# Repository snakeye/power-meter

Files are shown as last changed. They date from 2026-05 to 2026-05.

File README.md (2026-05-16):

# Power Meter

Power Meter is a microcontroller-based current consumption meter.
It samples current with an external ADC, computes rolling values in firmware, and displays live readings on a small OLED screen.

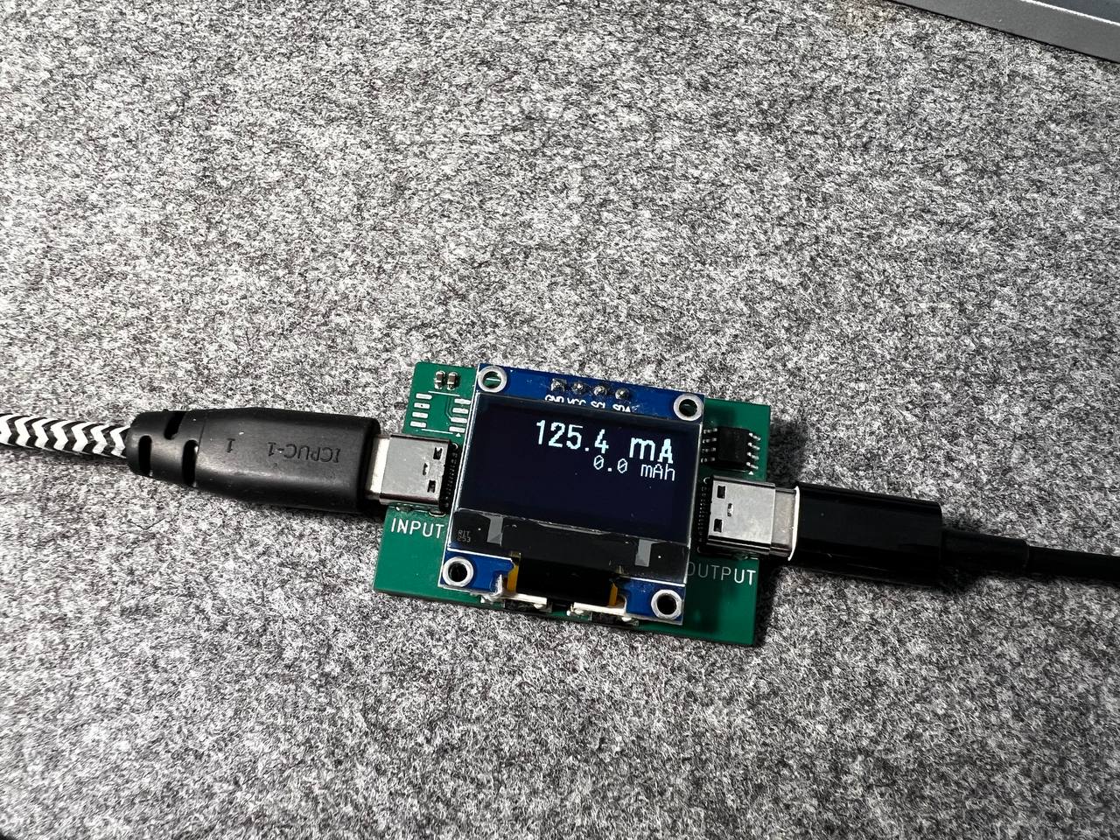
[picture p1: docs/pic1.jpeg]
The device


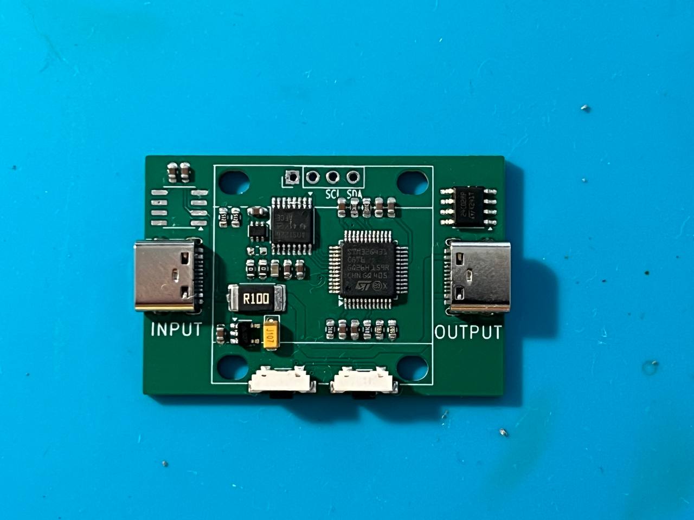
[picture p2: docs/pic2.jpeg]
PCB


This repository is organized around two parts:
- `firmware/` - PlatformIO project with STM32 firmware
- `hardware/` - KiCad schematic/PCB and symbol/footprint libraries

## Project status

This is an early public version. Core measurement and display flow is implemented, while some features are still work in progress.

Implemented:
- ADC continuous sampling using ADS1220 DRDY interrupt
- Raw-to-current conversion (microamps)
- On-screen display of averaged current, elapsed time, and accumulated charge estimate
- Reset of measurement session from button A

Not implemented yet / needs refinement:
- Persistent configuration load/save (`loadConfig`, `saveConfig` are currently stubs)
- Button B action (handler is empty)
- Charge accumulation algorithm validation and unit correctness improvements

## Quick start

Prerequisites:
- PlatformIO CLI installed
- ST-Link connected to target board

Build firmware:

```bash
cd firmware
platformio run
```

Flash firmware:

```bash
cd firmware
platformio run -t upload
```

Current default PlatformIO environment targets STM32G431C8 (`STM32G431C8T6`).

## Documentation

Use these documents as the main reference:
- `docs/overview.md` - project overview and data flow
- `docs/architecture.md` - system architecture and runtime model
- `docs/firmware.md` - firmware modules and behavior
- `docs/hardware.md` - hardware components and repository artifacts
- `docs/build-and-flash.md` - setup, build, flash, and debug workflow
- `docs/roadmap.md` - known issues and next milestones

## Notes for contributors

- Prefer documenting real current behavior over intended behavior.
- Keep units explicit (`uA`, `mA`, `mAh`, `us`, `ms`) in code and docs.
- If you change measurement math, update `docs/firmware.md` accordingly.

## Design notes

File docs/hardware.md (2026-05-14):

## Hardware

Hardware design files are stored in `hardware/` and maintained in KiCad format.

## Main components

- ADS1220 - 24-bit external ADC for precision sampling
- INA213 - current-sense amplifier
- 0.1 Ohm shunt resistor (100 mOhm)
- STM32 microcontroller (firmware currently targets STM32G431C8)
- 128x64 I2C OLED display (SSD1306 compatible)
- M24C02 external I2C EEPROM for config persistence
- Two user buttons (A/B)

## External EEPROM (M24C02)

Configuration persistence uses a discrete `M24C02` connected to the main I2C bus.

- Device type: `M24C02` (`2 Kbit = 256 bytes`)
- I2C base address: `0x50`
- Address pins: `A0/A1/A2 -> GND` (fixed address `0x50`)
- Typical page size: `8 bytes` (page write boundary must be respected)

Firmware write behavior:

- Data is split into 8-byte page writes.
- After each page write, firmware waits for device ready using ACK polling.
- Config data includes CRC32 to detect corruption.

Because OLED display shares the same I2C bus, EEPROM writes should remain infrequent (configuration or calibration events only).

## Measurement chain and equations

Current measurement path in this project:

1. Load current flows through shunt resistor.
2. Shunt creates a differential voltage proportional to current.
3. INA213 amplifies this shunt voltage.
4. ADS1220 digitizes amplified analog voltage.
5. Firmware converts ADC counts to current in `uA`.

Core equations:

- `Vshunt = Iload * Rshunt`
- `Vamp = GainINA * Vshunt = Iload * Rshunt * GainINA`
- `raw ~= (Vamp / Vref) * 2^23`
- `Iload = raw * Vref / (Rshunt * GainINA * 2^23)`

For the current firmware constants:

- `Rshunt = 0.1 Ohm`
- `GainINA = 50`
- `Vref = 2.048 V` (ADS1220 internal reference)
- `2^23 = 8,388,608`

Current per ADC count:

- `I_per_count = Vref / (Rshunt * GainINA * 2^23)`
- `I_per_count = 2.048 / (0.1 * 50 * 8,388,608) A`
- `I_per_count ~= 4.8828125e-8 A`
- `I_per_count ~= 48.828125 nA ~= 0.048828125 uA`

Counts per milliamp:

- `raw_per_mA = 0.001 / I_per_count`
- `raw_per_mA ~= 20,480 counts/mA`

Equivalent check values:

- `10 mA` -> about `204,800` counts
- `100 mA` -> about `2,048,000` counts
- `500 mA` -> about `10,240,000` counts (already above nominal 2^23 full scale and therefore limited by analog output swing and ADC range)

## Expected current range with INA213 at 3.3V

The practical upper current limit is usually set by INA213 output headroom before ADC full scale becomes the bottleneck.

Idealized upper bound using output rail as limit:

- `Imax_theory = Vout_max / (Rshunt * GainINA)`
- With `Vout_max = 3.3V`: `Imax_theory = 3.3 / (0.1 * 50) = 0.66A`

Real analog front-end usually cannot swing exactly to the rail. Practical range is therefore lower.

Recommended engineering expectation:

- Typical safe range: about `0 ... 0.55A`
- Practical observed limit for many boards: about `0.55 ... 0.65A`

Exact value should be validated on the assembled board and across temperature.

## Resolution vs real accuracy

The ADC quantization step is very small (`~48.8 nA/count`), but system accuracy is dominated by analog and calibration effects, not by ADC LSB.

Primary contributors:

- Shunt tolerance: `0.5%` scale error baseline.
- INA gain error and drift: additional scale and temperature-dependent error.
- Zero offset and drift: dominant at low currents.
- Noise (INA + ADS1220 + layout/EMI): causes short-term fluctuation.

With current firmware defaults, `adcZeroOffset = 5600` counts corresponds to approximately:

- `5600 * 0.048828125 uA ~= 273.44 uA`

This means that without robust zero calibration, low-current measurements can have large relative error.

## Practical accuracy expectations (before full calibration)

These are engineering expectations for this architecture, not guaranteed specs.

- `0.5 ... 5 mA`: often offset/noise limited, relative error can be high.
- `5 ... 100 mA`: generally usable, accuracy improves as signal dominates offset.
- `100 ... 600 mA`: usually dominated by scale error (shunt tolerance + gain error), often in low single-digit percent range after basic zeroing.

To tighten numbers, perform board-level calibration with known current loads.

## Charge integration units and conversion

Correct physical integration is:

- `dQ = I * dt`

If firmware stores:

- `I` in `uA`
- `dt` in `us`

then accumulated charge unit is:

- `Q` in `uA*us`

Conversion to milliamp-hours:

- `1 mAh = 1000 uA * 3600 s`
- `1 s = 1,000,000 us`
- `1 mAh = 1000 * 3600 * 1,000,000 = 3,600,000,000,000 uA*us`

Therefore:

- `mAh = Q_uA_us / 3,600,000,000,000`

When implemented this way, accumulated charge is correctly tied to measured current and elapsed time and does not break when ADC sample rate changes.

## Calibration recommendations

For robust measurements, use at least a 3-point procedure:

1. Zero-current calibration: record and store offset after warm-up.
2. Mid-scale calibration: validate gain around a representative working current.
3. High-scale calibration: validate near upper operating current without clipping.

Suggested firmware calibration outputs:

- `adcZeroOffset` (offset term)
- gain correction factor (multiplicative term)

Re-run calibration when changing shunt value, analog supply conditions, PCB revision, or thermal environment.

## Repository artifacts

Primary KiCad project files:
- `hardware/power-meter.kicad_pro`
- `hardware/power-meter.kicad_sch`
- `hardware/power-meter.kicad_pcb`

Libraries and custom symbols/footprints:
- `hardware/power-meter.kicad_sym`
- `hardware/INA213BIDCKT.kicad_sym`
- `hardware/STM32G431.kicad_sym`
- `hardware/power-meter.pretty/`

## Consistency note

Earlier project notes referenced STM32F103. Current firmware configuration and board definition target STM32G431C8.

If you are assembling hardware, verify the exact MCU variant against both:
- firmware board config (`firmware/platformio.ini`, `firmware/boards/genericSTM32G431C8.json`)
- KiCad schematic and BOM

## Suggested hardware documentation additions

For future public releases, consider adding:
- validated BOM with manufacturer part numbers
- board revision history
- calibration/test procedure
- connector and pinout diagrams

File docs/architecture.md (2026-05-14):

## Architecture

This project is split into hardware design artifacts and firmware runtime logic.

## Top-level components

- `hardware/` contains the electrical design in KiCad.
- `firmware/` contains embedded software for acquisition, processing, and UI.

## Firmware module map

- `src/main.cpp`
  - System setup
  - Button event wiring
  - Main loop tick handlers
- `src/adc.h`, `src/adc.cpp`
  - ADS1220 setup
  - DRDY interrupt handler
  - Measurement buffers and counters
  - Session reset and charge accumulator state
- `src/display.h`, `src/display.cpp`
  - OLED init (U8g2)
  - Periodic rendering of values
- `src/util.h`, `src/util.cpp`
  - ADC raw count to current conversion
  - 64-bit microsecond timestamp helper
- `src/config.h`, `src/config.cpp`
  - Runtime config structure and defaults
  - Persistence API placeholders (currently not implemented)

## Runtime model

### Setup phase

`setup()` performs initialization in this order:

1. I2C bus init
2. Display init
3. ADC init and ADC runtime configuration
4. Button A and B setup + click callbacks
5. Config load (currently stubbed)
6. Measurement data reset

### Main loop phase

`loop()` does not poll ADC directly. It:

- Advances button state machines (`btnA.tick()`, `btnB.tick()`).
- Schedules periodic display updates every 100 ms via `RecurringTask::interval(100, displayUpdate)`.

### Interrupt-driven acquisition

The ADS1220 DRDY pin is attached to `onAdcDataReadyInterrupt()`.

For each sample:

1. Read raw ADC data.
2. Apply configured zero offset.
3. Clamp negative values to zero.
4. Convert to current (`uA`).
5. Store current and time interval in fixed-size ring buffers.
6. Update counters/index and charge accumulator state.

## State ownership

Acquisition state is global and mostly held in `adc.cpp`:

- `measurements[]`, `intervals[]`
- `last_measurement_idx`, `measurements_count`
- `totalCharge`
- `tsStart`

Display logic reads this shared state to render user-visible metrics.

## Concurrency notes

- Measurements are updated in interrupt context and read in main-loop context.
- Several shared fields are marked `volatile`, but there is no explicit critical section around multi-field snapshots.
- As the project evolves, consider atomic snapshot/copy strategy for display calculations.

## Known architecture gaps

- Persistence layer exists only as API shape.
- Input model currently uses one active action (button A reset).
- Charge accumulation semantics require verification and likely redesign.

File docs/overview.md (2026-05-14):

## Overview

Power Meter is an embedded current measurement device built around an STM32 microcontroller, an ADS1220 external ADC, and an INA213 current-sense amplifier.

The firmware continuously samples current, stores recent values in a small ring buffer, computes an average for display, and presents runtime information on a 128x64 OLED.

## Goals

- Measure low current consumption with better resolution than basic MCU ADC paths.
- Provide simple on-device readout for quick bench testing.
- Keep the firmware compact and easy to iterate.

## Repository structure

- `firmware/` - PlatformIO project (Arduino framework on STM32)
- `hardware/` - KiCad project files (schematic, PCB, symbols, footprints)
- `docs/` - project documentation

## High-level data flow

1. ADS1220 performs continuous conversions.
2. DRDY pin triggers an interrupt on each new sample.
3. Interrupt handler reads raw ADC data and applies zero offset.
4. Raw counts are converted to current in microamps (`uA`).
5. Sample and interval are written to ring buffers.
6. UI task periodically renders average current, elapsed time, and charge estimate.

## Current maturity snapshot

Working now:
- ADC interrupt-driven sampling
- Current conversion and averaging
- OLED rendering loop
- Session reset on button A click

Still pending:
- EEPROM-backed config persistence API (`loadConfig` / `saveConfig`)
- Button B feature
- Charge integration model review for physical correctness

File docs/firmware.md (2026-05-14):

## Firmware

Firmware lives in `firmware/` and is built with PlatformIO using the Arduino framework for STM32.

## Build configuration

Main config file: `firmware/platformio.ini`

Current defaults:
- Platform: `ststm32`
- Framework: `arduino`
- Upload/debug: `stlink`
- Default env: `STM32G431C8T6`

Available environments:
- `STM32G431C8T6` (default)
- `bluepill` (legacy/alternate)

Custom board definition:
- `firmware/boards/genericSTM32G431C8.json`

## External libraries

- `ADS1220_WE` - ADS1220 ADC driver
- `U8g2` - OLED graphics
- `OneButton` - debounced button events
- `RecurringTask` - periodic task helper
- `Wire`, `SPI` - bus interfaces

## Module behavior

### `main.cpp`

- Initializes buses and peripherals.
- Registers button click handlers.
- Calls `loadConfig()` and `adcResetData()`.
- Runs button tick logic and display update scheduler in `loop()`.

Button actions:
- Button A click: resets current session data.
- Button B click: currently no action.

### `adc.cpp`

- Owns ADS1220 instance and SPI bus binding.
- Configures ADC for continuous conversion mode.
- Attaches falling-edge interrupt on DRDY.
- Converts raw ADC values to current via `convertRawToCurrent_uA()`.
- Stores values in fixed-size ring buffers (`measurements_buffer_size = 20`).

Data kept in global state:
- Samples: `measurements[]` in `uA`
- Per-sample delta: `intervals[]` in `us`
- Counters: `last_measurement_idx`, `measurements_count`
- Session start: `tsStart` in `ms`
- Accumulator: `totalCharge` (currently used as displayed charge estimate)

### `display.cpp`

- Uses `U8G2_SSD1306_128X64_NONAME_F_HW_I2C`.
- Computes average current over available ring buffer entries.
- Renders:
  - average current in `mA` with one decimal
  - charge estimate in `mAh` with one decimal (from `totalCharge` in `uA*us`)
  - elapsed time as `HH:MM:SS`

Refresh cadence is controlled externally from `loop()` at 100 ms.

### `util.cpp`

- `convertRawToCurrent_uA(rawValue)` converts ADC counts to microamps using:
  - reference voltage (`config.referenceVoltage`, mV)
  - INA213 gain (`ina213gain`)
  - shunt resistance (`shuntResistance`, mOhm)
  - ADC resolution (`2^23`)
- `get64bitMicros()` extends Arduino `micros()` to a monotonic 64-bit timeline using overflow tracking.

### `config.cpp`

- Declares default runtime config values:
  - `referenceVoltage = 2048` mV
  - `adcZeroOffset = 5600`
  - `adcGain = 1`
- Uses external I2C EEPROM `M24C02` at address `0x50` (A0/A1/A2 tied to GND).
- Stores config as a versioned block with CRC32 validation.
- `loadConfig()` reads from EEPROM, validates header/ranges/CRC, and falls back to defaults on failure.
- `saveConfig()` writes config using 8-byte page writes with ACK polling.

Stored block layout:

- `magic` (`0x504D4346`)
- `version` (`1`)
- `reserved`
- `Config`
- `crc32` (computed over all previous bytes in block)

## Pin mapping

Defined in `firmware/src/config.h`:

- I2C: `PA8` (SDA), `PA9` (SCL)
- ADS1220 SPI: `PA15` (CS), `PB3` (SCK), `PB4` (MISO), `PB5` (MOSI)
- ADS1220 DRDY: `PB15`
- Buttons: `PB7` (A), `PB9` (B)

## Known limitations

- UI and ISR share state without explicit snapshot synchronization.
- ADC error handling/recovery paths are minimal.

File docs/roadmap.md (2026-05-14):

## Roadmap

This roadmap reflects the current codebase state and practical next steps.

## Near-term priorities

1. Implement configuration persistence
   - Complete `loadConfig()` / `saveConfig()` with EEPROM layout and CRC validation.
   - Add safe defaults and versioning for future config changes.

2. Validate and fix charge accumulation
   - Revisit integration math and target units.
   - Add tests or offline validation scripts with known waveforms.

3. Complete input model
   - Define button B function (for example mode switch, calibration, or hold/reset behavior).
   - Add user feedback on screen for state changes.

4. Improve ISR/main-loop data consistency
   - Introduce snapshot logic or lock-free pattern for coherent display reads.
   - Reduce risk of partial multi-variable reads during rendering.

## Mid-term improvements

- Calibration workflow for zero offset and scaling factors
- Error detection and recovery (ADC init/read failures)
- Optional serial telemetry export for logging
- Power and noise characterization documentation

## Public-project readiness

- Add LICENSE file
- Add CONTRIBUTING guide
- Add issue templates for bug reports and feature requests
- Add hardware revision and tested setup matrix

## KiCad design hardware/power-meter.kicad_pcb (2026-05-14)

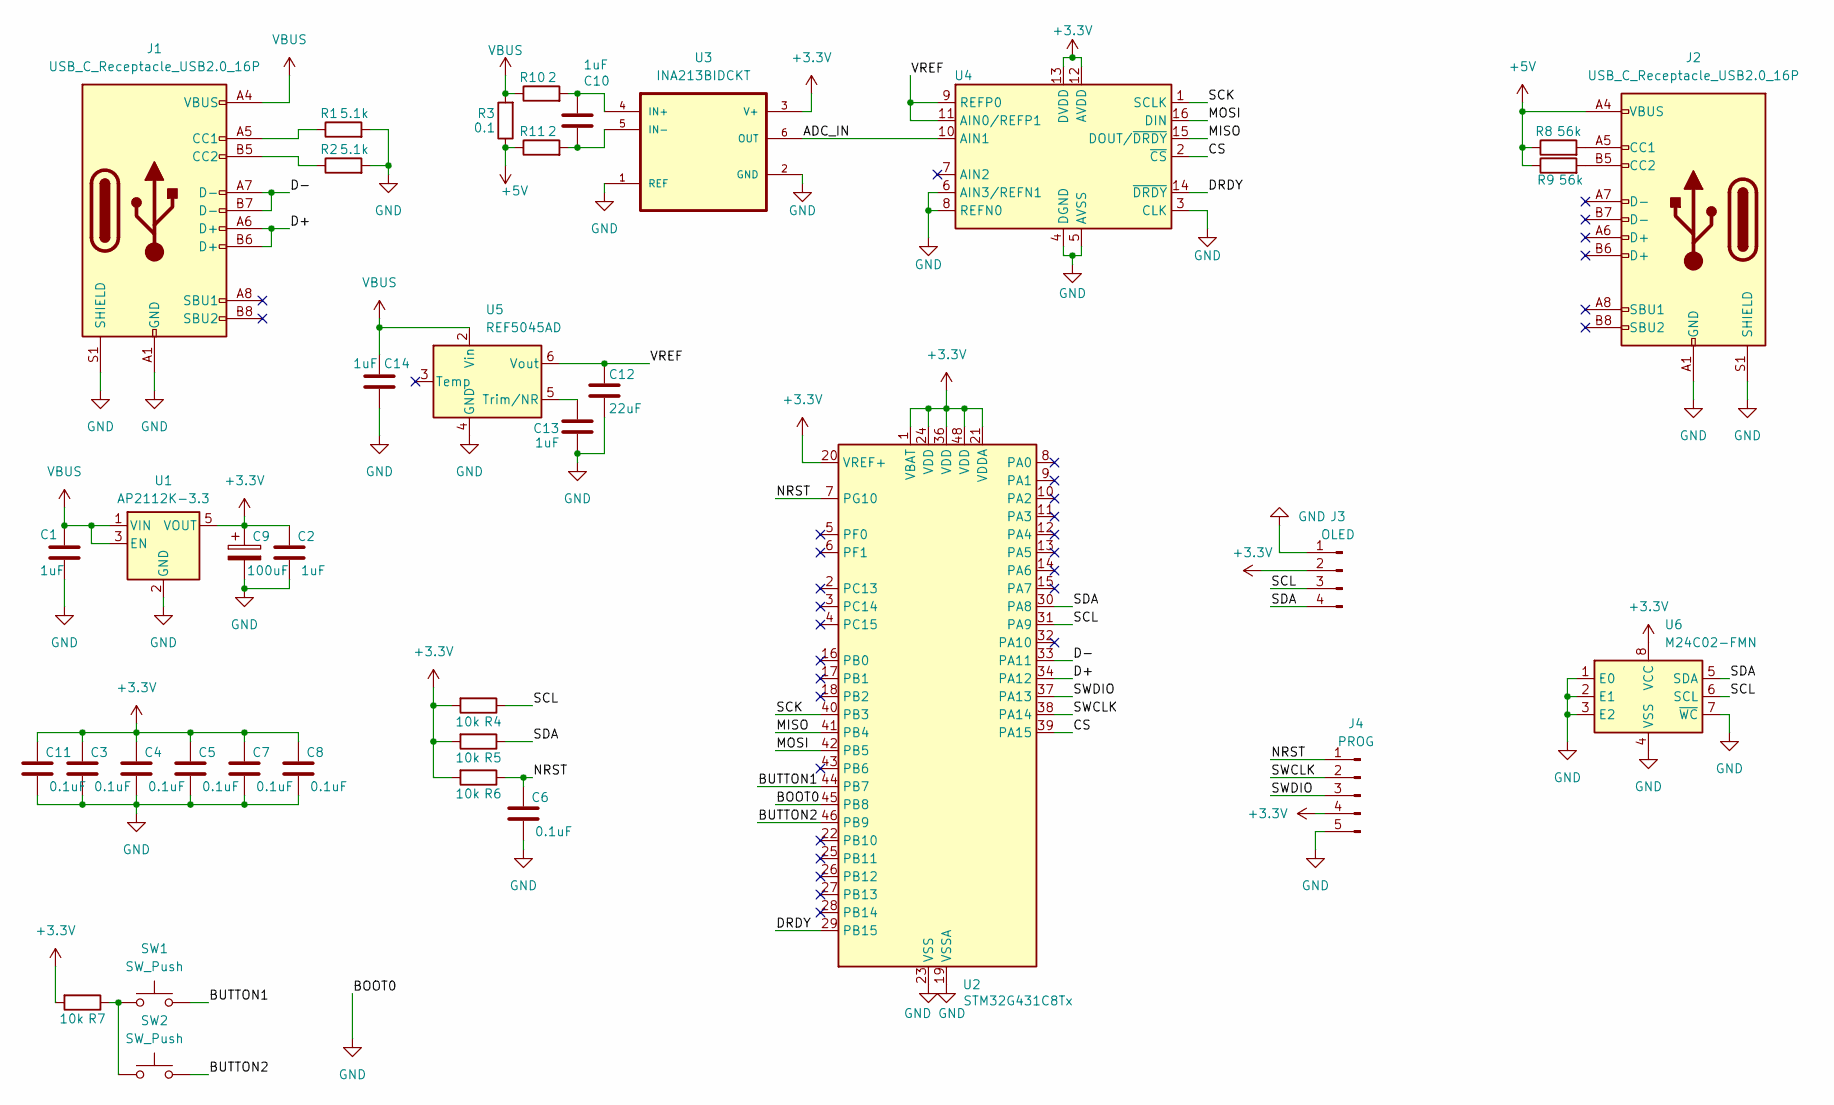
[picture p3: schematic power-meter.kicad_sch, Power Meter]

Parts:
C1, C2, C10, C13, C14: 1uF; C_0603_1608Metric
C3, C4, C5, C6, C7, C8, C11: 0.1uF; C_0603_1608Metric
C9: 100uF; CP_EIA-3216-18_Kemet-A
C12: 22uF; C_0603_1608Metric
J1, J2: USB_C_Receptacle_USB2.0_16P; USB_C_Receptacle_Palconn_UTC16-G
J3: OLED; Display_128x64_096_I2C
J4: PROG; PinSocket_1x05_P2.54mm_Vertical_SMD_Pin1Right
R1, R2: 5.1k; R_0603_1608Metric
R3: 0.1; R_2512_6332Metric
R4, R5, R6, R7: 10k; R_0603_1608Metric
R8, R9: 56k; R_0603_1608Metric
R10, R11: 2; R_0603_1608Metric
SW1, SW2: SW_Push; BUTTON
U1: AP2112K-3.3; SOT-23-5
U2: STM32G431C8Tx; LQFP-48_7x7mm_P0.5mm
U3: INA213BIDCKT; SOT-363_SC-70-6
U4: ADS1220xPW; TSSOP-16_4.4x5mm_P0.65mm
U5: REF5045AD; SOIC-8_3.9x4.9mm_P1.27mm
U6: M24C02-FMN; SOIC-8_3.9x4.9mm_P1.27mm

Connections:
+3.3V: C2.1, C3.1, C4.1, C5.1, C7.1, C8.1, C9.1, C11.1, J3.2, J4.4, R4.2, R5.2, R6.2, R7.2, U1.5 (VOUT), U2.1 (VBAT), U2.20 (VREF+), U2.21 (VDDA), U2.24 (VDD), U2.36 (VDD), U2.48 (VDD), U3.3 (V+), U4.12 (AVDD), U4.13 (DVDD), U6.8 (VCC)
+5V: J2.A4 (VBUS), J2.A9 (VBUS), J2.B4 (VBUS), J2.B9 (VBUS), R3.1, R8.1, R9.1, R11.1
/ADC_IN: U3.6 (OUT), U4.10 (AIN1)
/BUTTON1: SW1.2, U2.44 (PB7)
/BUTTON2: SW2.2, U2.46 (PB9)
/CS: U2.39 (PA15), U4.2 (~CS)
/D+: J1.A6 (D+), J1.B6 (D+), U2.34 (PA12)
/D-: J1.A7 (D-), J1.B7 (D-), U2.33 (PA11)
/DRDY: U2.29 (PB15), U4.14 (~DRDY)
/MISO: U2.41 (PB4), U4.15 (DOUT/~DRDY)
/MOSI: U2.42 (PB5), U4.16 (DIN)
/NRST: C6.1, J4.1, R6.1, U2.7 (PG10)
/SCK: U2.40 (PB3), U4.1 (SCLK)
/SCL: J3.3, R4.1, U2.31 (PA9), U6.6 (SCL)
/SDA: J3.4, R5.1, U2.30 (PA8), U6.5 (SDA)
/SWCLK: J4.2, U2.38 (PA14)
/SWDIO: J4.3, U2.37 (PA13)
/VREF: C12.1, U4.9 (REFP0), U4.11 (AIN0/REFP1), U5.6 (Vout)
GND: C1.2, C2.2, C3.2, C4.2, C5.2, C6.2, C7.2, C8.2, C9.2, C11.2, C12.2, C13.2, C14.2, J1.A1 (GND), J1.A12 (GND), J1.B1 (GND), J1.B12 (GND), J1.S1 (SHIELD), J2.A1 (GND), J2.A12 (GND), J2.B1 (GND), J2.B12 (GND), J2.S1 (SHIELD), J3.1, J4.5, R1.2, R2.2, U1.2 (GND), U2.19 (VSSA), U2.23 (VSS), U2.35 (VSS), U2.45 (PB8), U2.47 (VSS), U3.1 (REF), U3.2 (GND), U4.3 (CLK), U4.4 (DGND), U4.5 (AVSS), U4.6 (AIN3/REFN1), U4.8 (REFN0), U5.4 (GND), U6.1 (E0), U6.2 (E1), U6.3 (E2), U6.4 (VSS), U6.7 (~WC)
unnamed: J1.A5 (CC1), R1.1
unnamed: J1.B5 (CC2), R2.1
unnamed: J2.A5 (CC1), R8.2
unnamed: J2.B5 (CC2), R9.2
unnamed: R7.1, SW1.1, SW2.1
unnamed: C10.1, R10.2, U3.4 (IN+)
unnamed: C10.2, R11.2, U3.5 (IN-)
unnamed: C13.1, U5.5 (Trim/NR)
VBUS: C1.1, C14.1, J1.A4 (VBUS), J1.A9 (VBUS), J1.B4 (VBUS), J1.B9 (VBUS), R3.2, R10.1, U1.1 (VIN), U1.3 (EN), U5.2 (Vin)

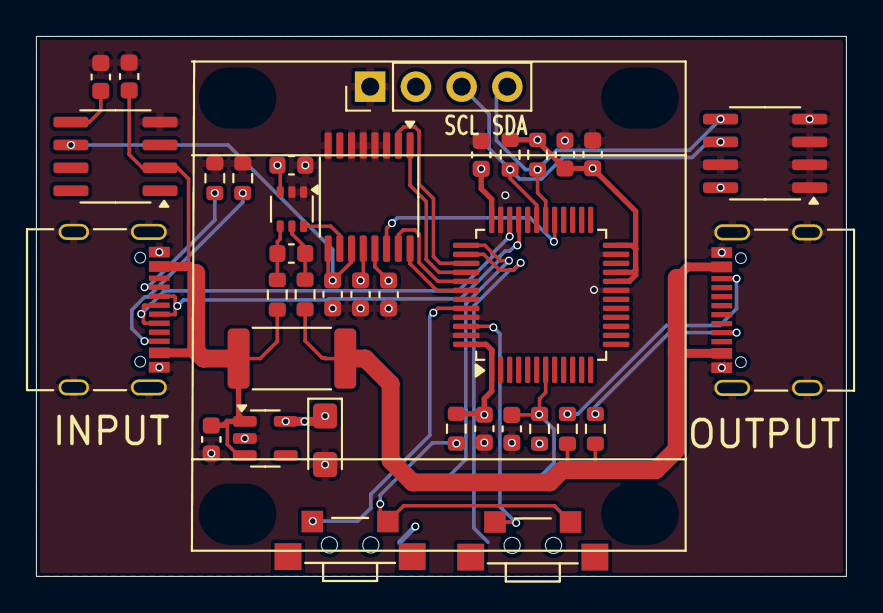
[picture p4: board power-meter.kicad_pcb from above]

Board: 4 copper layers, 45.0 x 30.0 mm, 37 parts (1 on the bottom side), 28 nets.

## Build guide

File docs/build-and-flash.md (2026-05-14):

## Build and Flash

This guide describes a minimal workflow for building and flashing firmware with PlatformIO.

## Prerequisites

- Python + PlatformIO CLI installed
- ST-Link probe connected
- Target board powered and wired

## Install PlatformIO CLI

If PlatformIO is not installed:

```bash
pip install platformio
```

## Build

From repository root:

```bash
cd firmware
platformio run
```

Build for a specific environment:

```bash
platformio run -e STM32G431C8T6
```

## Flash

```bash
cd firmware
platformio run -t upload
```

Flash a specific environment:

```bash
platformio run -e STM32G431C8T6 -t upload
```

## Serial monitor (optional)

If serial logging is added later:

```bash
platformio device monitor
```

## Debugging

The project is configured for ST-Link debug tool in `platformio.ini`.

Typical start:

```bash
platformio debug
```

## Troubleshooting

- Upload fails: verify SWD wiring and target power.
- Probe not found: check `stlink` connectivity and USB permissions.
- Wrong MCU behavior: confirm selected environment and board definition.
- Build mismatch: make sure local edits match `firmware/boards/genericSTM32G431C8.json`.

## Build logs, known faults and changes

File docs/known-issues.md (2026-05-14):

## Known issues

This file tracks confirmed firmware/hardware behavior problems with measurable impact.

---

### PM-FW-001 - Incorrect charge integration formula

- Severity: Critical
- Status: Fixed, pending bench validation
- Affected files: `firmware/src/adc.cpp`

Symptom:

- Accumulated charge grows incorrectly or almost does not grow for low currents.

Root cause:

- Firmware currently uses `current / tsDiff` instead of `current * tsDiff` in the charge accumulator.

Why this is incorrect:

- Physical relation is `dQ = I * dt`.
- Dividing by time computes a rate-like term, not charge increment.

Impact:

- Capacity (`mAh`) display is mathematically invalid.
- Result depends heavily on sample interval and can collapse near zero.

Fix direction:

- Replace integration step with multiplication: `Q += I * dt`.
- Keep units explicit and consistent (`uA`, `us`, `uA*us`).

Fix applied:

- `firmware/src/adc.cpp` now accumulates as `totalCharge += uint64_t(current) * uint64_t(tsDiff)`.
- Commit: `a1aa619`.

Acceptance criteria:

- Charge accumulation remains stable when ADC data rate (SPS) changes.
- Low current load (for example `~0.5 mA`) produces monotonic non-zero accumulation over time.

---

### PM-FW-002 - Wrong conversion factor from `uA*us` to `mAh`

- Severity: Critical
- Status: Fixed, pending bench validation
- Affected files: `firmware/src/display.cpp`

Symptom:

- Displayed `mAh` is scaled incorrectly by several orders of magnitude if `totalCharge` is in `uA*us`.

Root cause:

- Current divisor (`3600 * 1000`) corresponds to `uA*s -> mAh`, not `uA*us -> mAh`.

Correct conversion:

- `1 mAh = 3,600,000,000,000 uA*us`.

Fix direction:

- Use `mAh = totalCharge / 3600000000000ULL` when `totalCharge` is kept in `uA*us`.

Fix applied:

- `firmware/src/display.cpp` now uses `uA*us` scaling and displays `mAh` with one decimal using integer math (`deci-mAh`).
- Commit: `a1aa619` (+ post-commit UI precision update).

Acceptance criteria:

- Calculated capacity matches reference integration from logged current/time pairs.

---

### PM-FW-003 - Incorrect `printf` format for 64-bit value

- Severity: High
- Status: Fixed, pending bench validation
- Affected files: `firmware/src/display.cpp`

Symptom:

- Capacity output may appear valid in simple cases but is type-unsafe and can print corrupted values.

Root cause:

- `totalCharge` is `uint64_t`, but code uses `%d` which expects `int`.
- This is undefined behavior for variadic formatting.

Impact:

- Output can be platform/compiler dependent and break with argument layout changes.

Fix direction:

- Format with a type-compatible specifier or convert to a safe display type first.
- Recommended display path: compute `uint32_t mAh` after division, print as unsigned long-compatible argument.

Fix applied:

- Display path now prints pre-scaled 32-bit values with unsigned formatting.
- Commit: `a1aa619`.

Acceptance criteria:

- Output remains correct with multiple arguments in a single `printf` call.
- No compiler warnings for format/type mismatch.

---

### PM-FW-004 - Integer truncation sensitivity in old algorithm

- Severity: High
- Status: Fixed
- Affected files: `firmware/src/adc.cpp`

Symptom:

- Small-current contribution disappears due to integer division truncation.

Root cause:

- In the old division-based formula, fractional parts are discarded at each sample.

Impact:

- Strong underestimation of capacity, worst at low currents.

Fix direction:

- Remove division-based integrator.
- Preserve precision in 64-bit intermediate math when multiplying `current * tsDiff`.

Fix applied:

- Division-based integration removed.
- 64-bit multiplication is used for charge accumulation.
- Commit: `a1aa619`.

Acceptance criteria:

- Numerical simulation with fractional-step contributions no longer loses low-current energy over time.

---

## Verification checklist after fixes

- Test at low load (`~0.5 mA`): `mAh` must increase slowly but steadily.
- Test at moderate load (`~50-100 mA`): displayed accumulation should track expected runtime capacity.
- Repeat with at least two ADS1220 data rates: final integrated `mAh` should remain consistent within normal measurement error.
- Confirm no format warnings from compiler for display print calls.

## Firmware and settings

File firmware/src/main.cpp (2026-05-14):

#include <Arduino.h>
#include <Wire.h>

#include <U8g2lib.h>

#include <OneButton.h>

#include <RecurringTask.h>

#include "config.h"
#include "util.h"
#include "adc.h"
#include "display.h"

// Buttons
OneButton btnA;
OneButton btnB;

enum UiMode : uint8_t
{
    UI_MODE_RUN = 0,
    UI_MODE_MENU = 1,
};

enum MenuItem : uint8_t
{
    MENU_ITEM_RATE = 0,
    MENU_ITEM_CAL = 1,
    MENU_ITEM_EXIT = 2,
    MENU_ITEM_COUNT = 3,
};

UiMode uiMode = UI_MODE_RUN;
uint8_t menuItem = MENU_ITEM_RATE;

void updateMenuDisplay()
{
    displaySetMenuState(uiMode == UI_MODE_MENU, menuItem, adcGetRateMode());
}

void onBtnAClick()
{
    displayNotifyActivity();

    if (uiMode == UI_MODE_MENU)
    {
        menuItem = (menuItem + 1) % MENU_ITEM_COUNT;
        updateMenuDisplay();
        return;
    }

    adcResetData();
    displayShowStatus("RESET");
}

void onBtnBClick()
{
    displayNotifyActivity();

    if (uiMode != UI_MODE_MENU)
    {
        return;
    }

    switch (menuItem)
    {
    case MENU_ITEM_RATE:
    {
        uint8_t nextMode = (adcGetRateMode() + 1) % 3;
        if (adcSetRateMode(nextMode))
        {
            saveConfig();
            if (nextMode == 0)
            {
                displayShowStatus("RATE FAST");
            }
            else if (nextMode == 1)
            {
                displayShowStatus("RATE BAL");
            }
            else
            {
                displayShowStatus("RATE PREC");
            }
        }
        else
        {
            displayShowStatus("RATE ERR");
        }
        updateMenuDisplay();
        break;
    }
    case MENU_ITEM_CAL:
        if (adcCalibrateZeroOffset(128))
        {
            saveConfig();
            AdcCalibrationDiag diag = {};
            adcGetLastCalibrationDiag(&diag);

            char status[12] = {0};
            long span = (diag.span >= 0) ? diag.span : -diag.span;
            snprintf(status, sizeof(status), "O%ld S%ld", (long)diag.offset, span);
            uiMode = UI_MODE_RUN;
            updateMenuDisplay();
            displayShowStatus(status, 2500);
        }
        else
        {
            AdcCalibrationDiag diag = {};
            adcGetLastCalibrationDiag(&diag);

            char status[12] = {0};
            uiMode = UI_MODE_RUN;
            updateMenuDisplay();
            if (diag.timeout)
            {
                displayShowStatus("CAL TIME", 2500);
            }
            else
            {
                long span = (diag.span >= 0) ? diag.span : -diag.span;
                snprintf(status, sizeof(status), "NOISE %ld", span);
                displayShowStatus(status, 2500);
            }
        }
        break;
    case MENU_ITEM_EXIT:
    default:
        uiMode = UI_MODE_RUN;
        updateMenuDisplay();
        displayShowStatus("EXIT");
        break;
    }
}

void onBtnBLongPress()
{
    displayNotifyActivity();

    if (uiMode == UI_MODE_RUN)
    {
        uiMode = UI_MODE_MENU;
        menuItem = MENU_ITEM_RATE;
        updateMenuDisplay();
        displayShowStatus("MENU");
    }
    else
    {
        uiMode = UI_MODE_RUN;
        updateMenuDisplay();
        displayShowStatus("EXIT");
    }
}

void setup()
{
    Wire.begin(PIN_I2C_SDA, PIN_I2C_SCL);

    // display
    displayInit();
    displayNotifyActivity();

    // ADC
    adcInit();
    adcConfig();

    // buttons
    btnA.setup(PIN_BTN_A, INPUT_PULLDOWN, false);
    btnA.attachClick(onBtnAClick);

    btnB.setup(PIN_BTN_B, INPUT_PULLDOWN, false);
    btnB.attachClick(onBtnBClick);
    btnB.setPressMs(2000);
    btnB.attachLongPressStart(onBtnBLongPress);

    //
    loadConfig();
    adcApplyConfig();
    updateMenuDisplay();

    //
    adcResetData();
}

void loop()
{
    btnA.tick();
    btnB.tick();

    adcProcessPendingData();

    RecurringTask::interval(100, displayUpdate);
}

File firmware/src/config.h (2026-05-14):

#pragma once

#include <Arduino.h>

#define PIN_I2C_SDA PA8
#define PIN_I2C_SCL PA9

#define PIN_CS PA15
#define PIN_SCK PB3
#define PIN_MISO PB4
#define PIN_MOSI PB5
#define PIN_DRDY PB15

#define PIN_BTN_A PB7
#define PIN_BTN_B PB9

// Constants
constexpr int32_t shuntResistance = 100; // Shunt resistance, milliOhms
constexpr int32_t ina213gain = 50;       // Gain INA213

constexpr int32_t adcResolution = 1 << 23; // 2^23 for the 24-bit ADC, 8388608 counts.

//
struct Config
{
    int32_t referenceVoltage; // milliVolts
    int32_t adcZeroOffset;
    int32_t adcGain;
    uint8_t adcRateMode;
};

extern Config config;

bool loadConfig();
void saveConfig();

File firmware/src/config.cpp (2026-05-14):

#include <Arduino.h>
#include <Wire.h>

#include "config.h"

Config config = {
    .referenceVoltage = 2048,
    .adcZeroOffset = 5600,
    .adcGain = 1,
    .adcRateMode = 1,
};

namespace
{
    constexpr uint8_t eepromAddress = 0x50;
    constexpr uint16_t eepromSize = 256;
    constexpr uint8_t eepromPageSize = 8;
    constexpr uint32_t configMagic = 0x504D4346; // PMCF
    constexpr uint16_t configVersion = 2;

    struct ConfigBlock
    {
        uint32_t magic;
        uint16_t version;
        uint16_t reserved;
        Config config;
        uint32_t crc;
    };

    struct ConfigV1
    {
        int32_t referenceVoltage;
        int32_t adcZeroOffset;
        int32_t adcGain;
    };

    struct ConfigBlockV1
    {
        uint32_t magic;
        uint16_t version;
        uint16_t reserved;
        ConfigV1 config;
        uint32_t crc;
    };

    uint32_t crc32(const uint8_t *data, size_t len)
    {
        uint32_t crc = 0xFFFFFFFF;
        for (size_t i = 0; i < len; i++)
        {
            crc ^= data[i];
            for (int b = 0; b < 8; b++)
            {
                uint32_t mask = -(crc & 1U);
                crc = (crc >> 1) ^ (0xEDB88320 & mask);
            }
        }
        return ~crc;
    }

    bool eepromWaitReady(uint32_t timeoutMs = 20)
    {
        uint32_t start = millis();
        while ((millis() - start) < timeoutMs)
        {
            Wire.beginTransmission(eepromAddress);
            if (Wire.endTransmission() == 0)
            {
                return true;
            }
        }
        return false;
    }

    bool eepromRead(uint16_t addr, uint8_t *out, size_t len)
    {
        if (addr + len > eepromSize)
            return false;

        for (size_t offset = 0; offset < len;)
        {
            size_t remaining = len - offset;
            uint8_t chunk = uint8_t(remaining < 16 ? remaining : 16);

            Wire.beginTransmission(eepromAddress);
            Wire.write(uint8_t((addr + offset) & 0xFF));
            if (Wire.endTransmission(false) != 0)
                return false;

            uint8_t received = Wire.requestFrom(eepromAddress, chunk);
            if (received != chunk)
                return false;

            for (uint8_t i = 0; i < chunk; i++)
            {
                out[offset + i] = Wire.read();
            }

            offset += chunk;
        }

        return true;
    }

    bool eepromWritePage(uint16_t addr, const uint8_t *data, size_t len)
    {
        if (len == 0 || len > eepromPageSize)
            return false;

        if (addr + len > eepromSize)
            return false;

        Wire.beginTransmission(eepromAddress);
        Wire.write(uint8_t(addr & 0xFF));
        for (size_t i = 0; i < len; i++)
        {
            Wire.write(data[i]);
        }

        if (Wire.endTransmission() != 0)
            return false;

        return eepromWaitReady();
    }

    bool eepromWrite(uint16_t addr, const uint8_t *data, size_t len)
    {
        if (addr + len > eepromSize)
            return false;

        size_t offset = 0;
        while (offset < len)
        {
            uint16_t currentAddr = addr + offset;
            uint8_t pageOffset = currentAddr % eepromPageSize;
            size_t pageSpace = eepromPageSize - pageOffset;
            size_t remaining = len - offset;
            size_t chunk = pageSpace < remaining ? pageSpace : remaining;

            if (!eepromWritePage(currentAddr, data + offset, chunk))
                return false;

            offset += chunk;
        }

        return true;
    }

    bool validateConfigRange(const Config &c)
    {
        return c.referenceVoltage >= 1800 && c.referenceVoltage <= 2500 &&
               c.adcGain > 0 && c.adcGain <= 1000 &&
               c.adcZeroOffset >= -2000000 && c.adcZeroOffset <= 2000000 &&
               c.adcRateMode <= 2;
    }
}
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

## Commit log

2026-05-14 feat: v2
    Consolidate all work related to hardware revision v2 and firmware migration for that revision.
    Hardware scope:
    - Redesign PCB/schematic from v1 to v2 with updated component and connectivity decisions.
    - Add STM32G431 symbol/library assets used by the new design.
    - Integrate board-level corrections performed after first v2 routing pass.
    Firmware scope:
    - Migrate firmware target to STM32G431 platform and board configuration.
    - Update build configuration and platform definitions for the new MCU/board.
    - Adapt application logic to v2 hardware behavior and interfaces.
    - Refactor firmware from monolithic source into focused modules (adc/config/display/util).
    - Apply stabilizatio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
    [power-meter.kicad_pcb, power-meter.kicad_sch]
2026-05-14 feat: v1
    Consolidate all work related to hardware revision v1 and its initial firmware.
    - Add the first complete KiCad project for power-meter board revision v1.
    - Introduce custom symbols/footprints and library table configuration required for the design.
    - Capture iterative PCB/schematic adjustments made during board bring-up.
    - Apply power-path fix for OLED supply and related project updates.
    - Initialize PlatformIO-based firmware project structure.
    - Add initial display integration and baseline application entry point.
    - Implement early ADC measurement flow and button handling logic.
    - Include incremental bring-up fixes required to run on v1 hard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
    [power-meter.kicad_pcb, power-meter.kicad_sch]
2026-05-14 fix: harden ADC data path against races and move SPI work out of ISR (#2)
    * fix: correct charge integration and mAh conversion
    Use physically correct I*dt accumulation, fix uA*us to mAh scaling, and add hardware math plus known-issues documentation to support calibration and validation.
    * feat: add M24C02 config persistence and improve capacity display
    Persist runtime config to external I2C EEPROM with CRC validation and page writes, and show charge as one-decimal mAh for better low-current visibility.
    * feat: add raw ADC zero calibration on button hold
    Calibrate zero offset from stable raw ADS1220 samples on 2s button B hold, persist it to EEPROM, and show short status messages for res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
    [adc.cpp, config.cpp, display.cpp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]
2026-05-14 feat: add ADC settings menu and calibration diagnostics
2026-05-16 docs: Added device picture
